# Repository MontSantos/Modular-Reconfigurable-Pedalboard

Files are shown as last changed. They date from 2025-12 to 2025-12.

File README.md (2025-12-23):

# Modular Reconfigurable Pedalboard
A modular, reconfigurable guitar/bass pedalboard designed as a **universal base** for **interchangeable effect modules**.  
Current version includes two analog effect circuits: an **MXR-style Distortion+ inspired clone** and a **silicon Fuzz Face–inspired fuzz**.

---

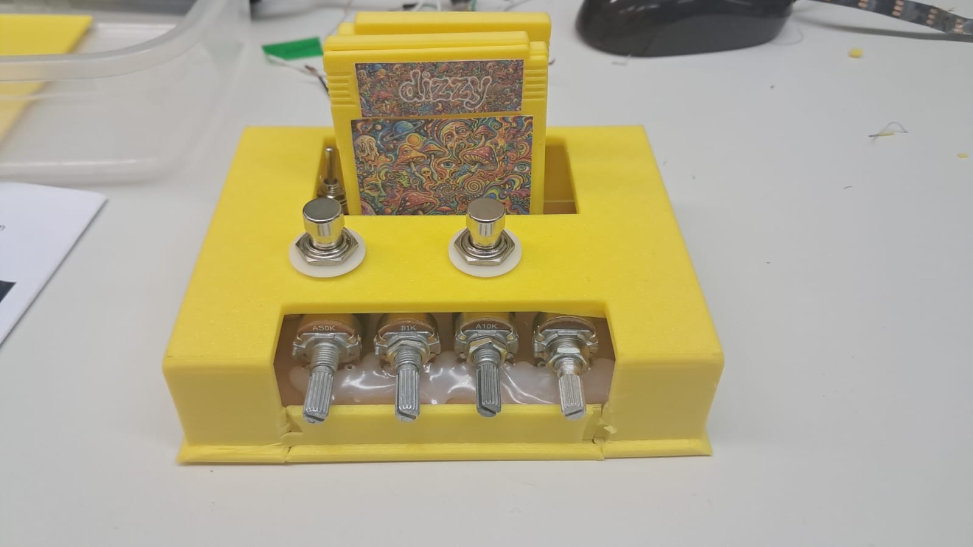
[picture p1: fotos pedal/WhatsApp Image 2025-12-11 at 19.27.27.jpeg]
Pedalboard photo


---

## Features (current)

- A modular board capable of hosting **two 8 pin effect modules** simultaneously
- Two analog effect modules included:
  - **MXR-style distortion** (Distortion+/D+ family inspiration)
  - **Silicon Fuzz Face–inspired fuzz**
- Each module supports **up to two PCB-mounted potentiometers** for onboard control (e.g., Gain/Level, Fuzz/Volume)
- Designed for common use with string instruments, such as **electric guitars** or **basses**
- Fully **customizable** and **open-source** for public access

---

## Repository structure

- `Imagens cartuchos/` - Presents the cover images and logos used to decorate the cartridges
- `PlacaGeral/` — The **main board** (the “placão”): carrier/backplane PCB that hosts the modules and concentrates the shared wiring.
- `Pedais/` — The **effect modules** (schematics/PCB files for Dizzy and Amorphous, and future modules).
- `Modelos pedal/` — Mechanical assets (e.g., templates, outlines, 3D/visual models, and design references).
- `fotos pedal/` — Build photos and progress shots used in the README and documentation.
  
---

## Included effect modules

### 1) **Dizzy** - Silicon Fuzz Face–inspired fuzz 

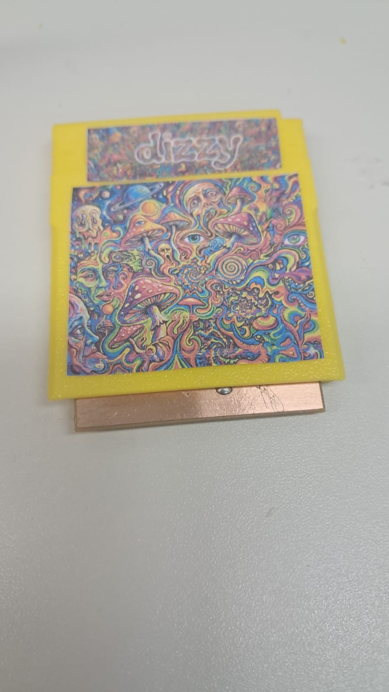
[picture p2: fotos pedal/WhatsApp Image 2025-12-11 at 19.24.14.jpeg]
dizzy


A two-transistor silicon fuzz, implemented with a **negative-ground** power scheme for easy integration with other pedal models.
Great for raw, dirty and aggressive tones.

This module is nicknamed **Dizzy**, referencing the fuzz’s naturally **psychedelic, dizzy aesthetic**.

Reference / inspiration:
- Fuzz Central (Fuzz Face): https://fuzzcentral.ssguitar.com/fuzzface.php

### 2) **Amorphous** - MXR-style distortion (Distortion+ inspired)

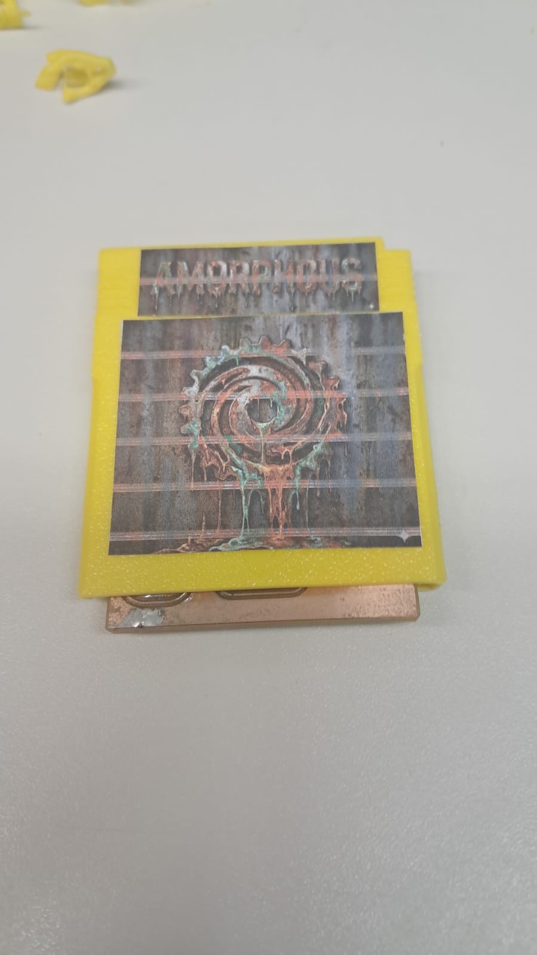
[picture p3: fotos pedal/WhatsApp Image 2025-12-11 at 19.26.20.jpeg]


A classic op-amp gain stage with germanium diode clipping (the “raw” distortion character).  
Useful for gritty tones.  

This module is nicknamed **Amorphous**, referencing how distortion/clipping turns a clean waveform into a denser, less-defined shape.

Reference / inspiration:
- Electrosmash analysis: https://www.electrosmash.com/mxr-distortion-plus-analysis

## The **Main Board**

The **PlacaGeral** is the carrier PCB that turns this project into a modular system. In practice, it works like a small “backplane” for pedals:

- Provides **two module slots** (two 8-pin effect modules at the same time)
- Routes **audio I/O** and keeps a consistent grounding scheme across modules
- Distributes **9V DC power** to the modules (the main board is **center-positive** oriented — double-check before powering)
- Offers a standardized mechanical/electrical base so modules can be swapped without rewiring the whole pedalboard

> ⚠️ Many common pedal supplies are **center-negative**. Do **not** plug a standard center-negative supply into a center-positive board without an adapter/inverter — unless you want to release the magic smoke (and smell something funny).

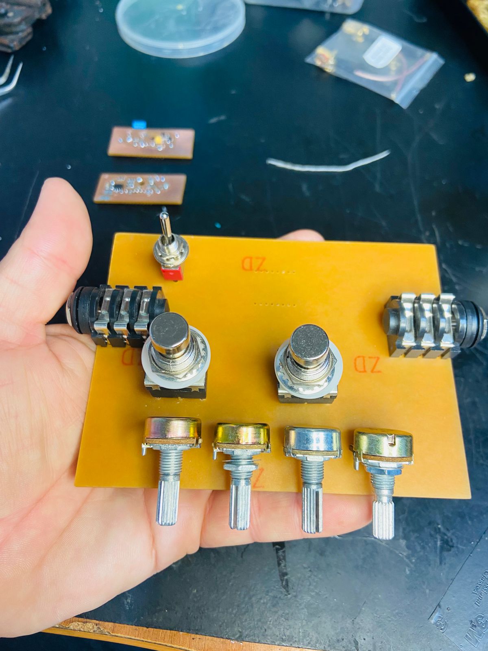
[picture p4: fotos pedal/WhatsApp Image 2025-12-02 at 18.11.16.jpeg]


---

## Cartridge (module holder)

Each effect module is mounted on a removable 3d printed Gameboy inspired **cartridge**, which provides mechanical support and keeps the 8-pin module interface consistent across pedals.

This cartridge was adapted from an existing model available at **(link)** and then modified for this project (fit/clearance/alignment), including:
- alignment tweaks in order to support pedals PCBs.
- clearance changes to avoid collisions with tall components, and parts of the main board structure

Reference / inspiration:
 - [(link)](https://grabcad.com/library/original-gameboy-cartridge)

---

## Power & safety notes

- **Verify supply voltage (9V DC) and polarity** before connecting any power source.
- Before first power-up:
  - Confirm electrolytic/tantalum capacitors orientations.
  - Verify power supply polarity: the main board is **center-positive** oriented.
 
## 3D printed structures notes

It was necessary to modify the case of the **Main board** to accommodate the final board layout. The front piece of the case was cut so the potentiometers could fit in the case. The removed piece was then put back in place once the circuit board was in position.
 
## Electronics hardware notes

During initial bring-up, the main board required a small routing correction: 
 - To properly route the **effect IN/OUT** of each module, it is necessary **cut two traces per pedal** (one affecting the input path and one affecting the output path).  
 - To fix the audio routing, the board was **rewired** (trace cuts + jumper wires) for each module’s input and output.
 - Additionally, the two buffers were removed because they were not handling the signal swing correctly and ended up clipping the **negative half-cycle** of the waveform. This change restored a more symmetric signal path.
This was a quick rework step applied on the assembled board and will be addressed in the next PCB revision.

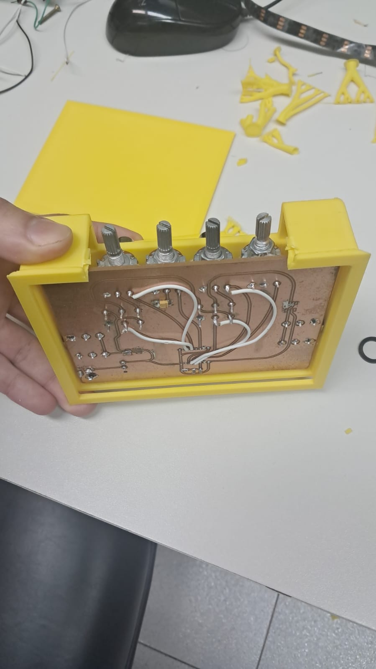
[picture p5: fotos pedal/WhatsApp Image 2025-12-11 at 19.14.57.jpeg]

 
## Credits / Contributions

- **João Neto** — Pedal testing and validation **before** assembling the PCBs (pre print tests).
- **Guilherme Santos** — Pedal testing and validation **before** assembling the PCBs (pre print tests); **PCB design**, **assembly**, and **final testing** of the system.
- **Romulo Soli** — **3D modeling** (enclosure/mechanical models).
- **Yanis** -

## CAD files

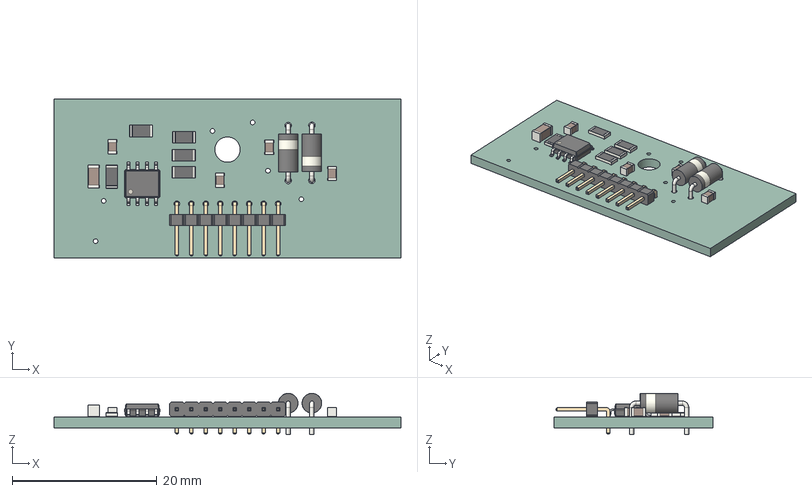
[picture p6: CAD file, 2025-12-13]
Modelos pedal/Modelos pcb/MXRpedal.step
48.0 x 22.0 x 5.71 mm
D_A-405_P7.62mm_Horizontal x 2
R_1206_3216Metric x 5
PinHeader_1x08_P2.00mm_Horizontal
C_0805_2012Metric x 4
C_1206_3216Metric
SOIC-8_3.9x4.9mm_P1.27mm
MXRpedal_PCB

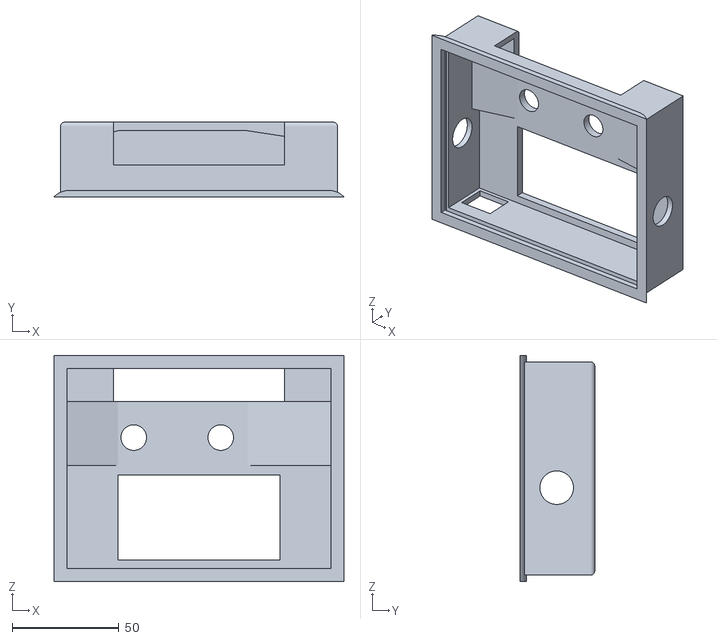
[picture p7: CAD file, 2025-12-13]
Modelos pedal/Modelos STL/SupaCaixa.STL
136.0 x 35.0 x 106.0

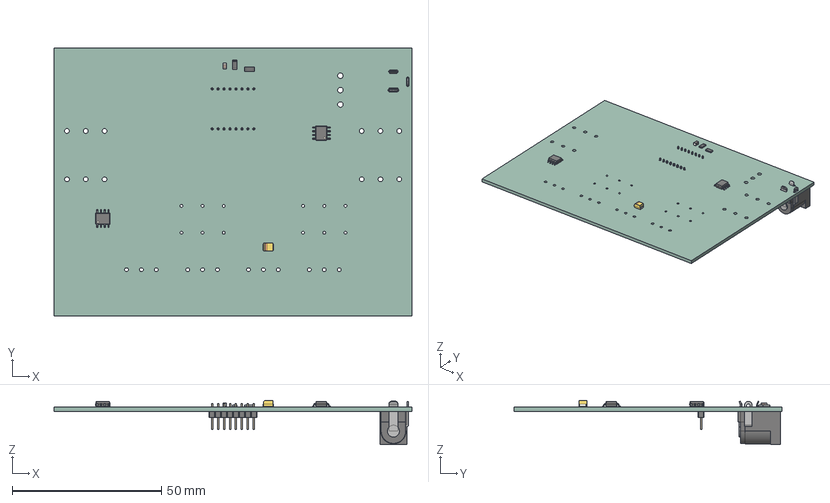
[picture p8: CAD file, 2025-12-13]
Modelos pedal/Modelos pcb/PlacaGeral.step
120.0 x 90.0 x 14.8 mm
R_1206_3216Metric x 2
SOIC-8_3.9x4.9mm_P1.27mm x 2
CP_EIA-3528-21_Kemet-B
C_0805_2012Metric
PinHeader_1x08_P2.00mm_Vertical x 2
BarrelJack_GCT_DCJ200-10-A_Horizontal
PlacaGeral_PCB

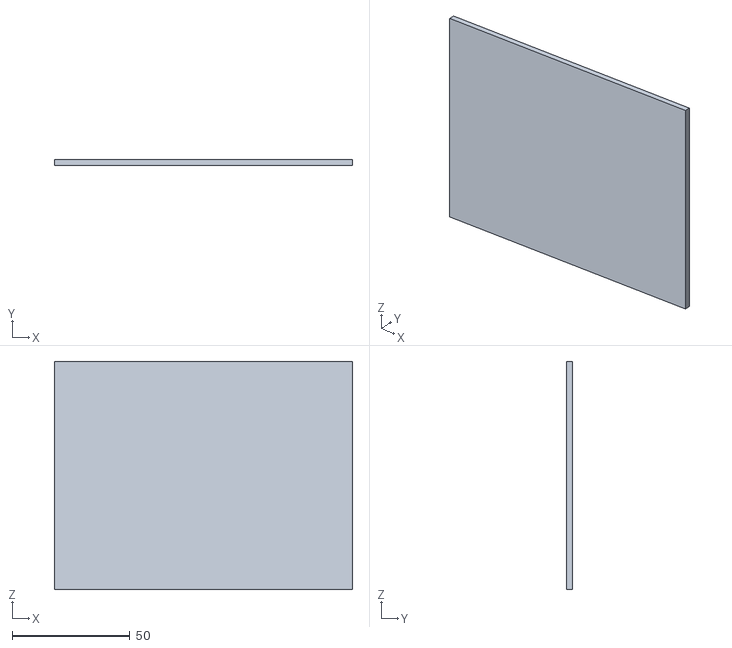
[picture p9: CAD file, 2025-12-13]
Modelos pedal/Modelos STL/CaixaFundo.STL
126.6 x 2.60 x 97.0

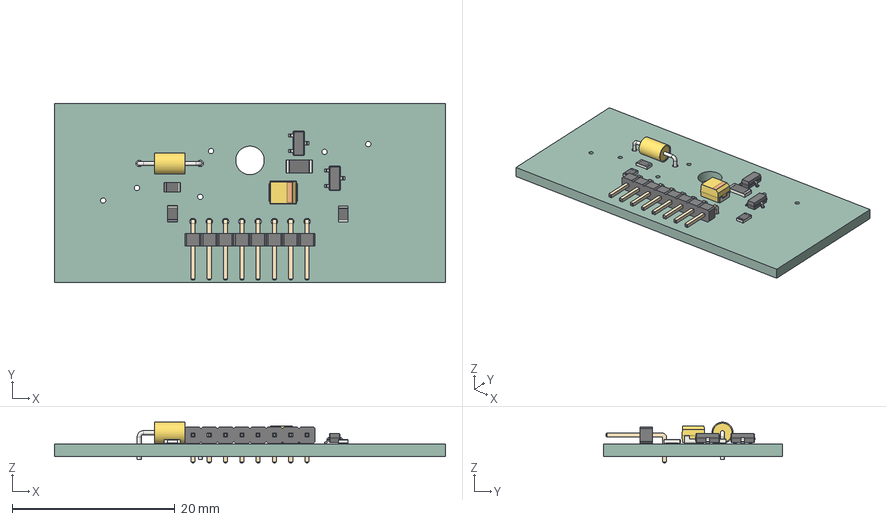
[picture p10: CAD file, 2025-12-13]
Modelos pedal/Modelos pcb/FuzzFace.step
48.0 x 22.0 x 5.00 mm
PinHeader_1x08_P2.00mm_Horizontal
R_1206_3216Metric
R_0805_2012Metric x 3
C_Axial_L3.8mm_D2.6mm_P7.50mm_Horizontal
SOT-23 x 2
CP_EIA-3528-21_Kemet-B
FuzzFace_PCB

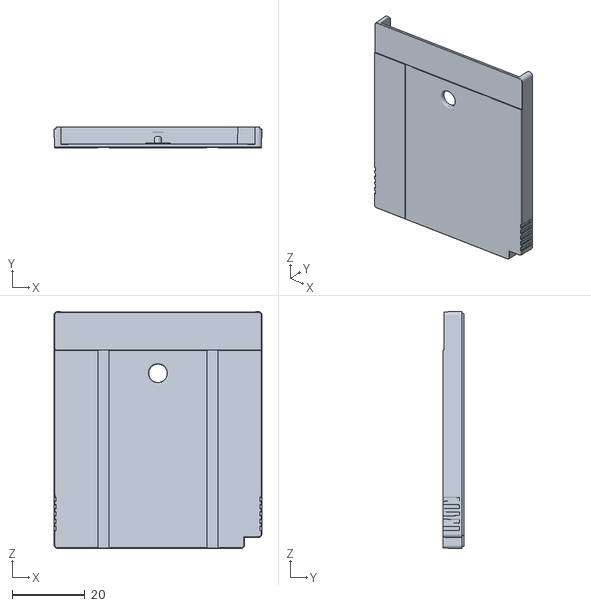
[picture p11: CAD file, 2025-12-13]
Modelos pedal/Modelos STL/GB-Cart_Bottom.stl
57.0 x 5.75 x 65.0

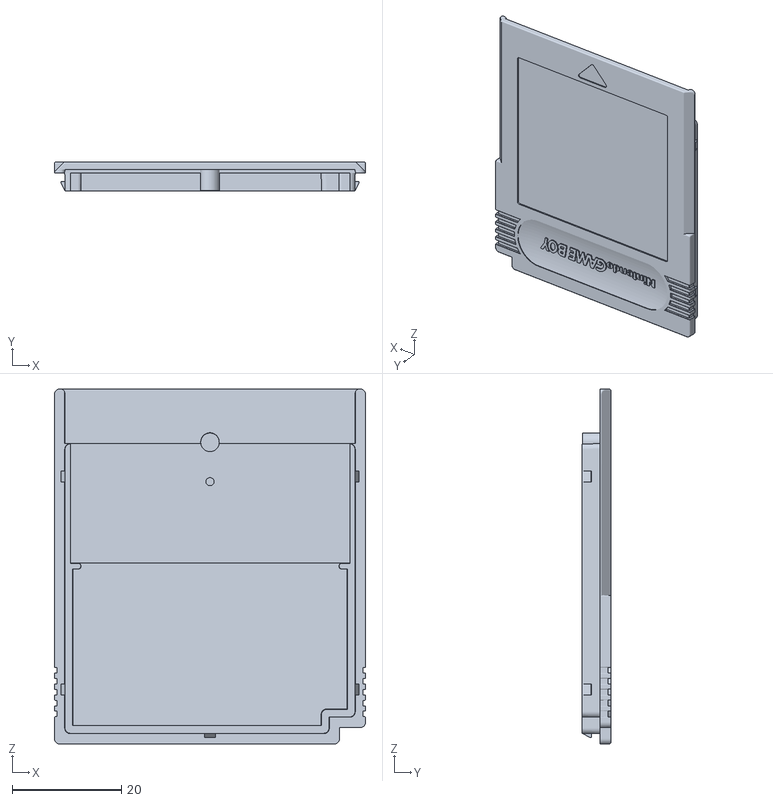
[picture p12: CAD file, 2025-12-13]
Modelos pedal/Modelos STL/GB-Cart_Top.stl
57.0 x 5.30 x 65.0

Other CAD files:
Modelos pedal/Modelos pcb/PlacaGeral.stl

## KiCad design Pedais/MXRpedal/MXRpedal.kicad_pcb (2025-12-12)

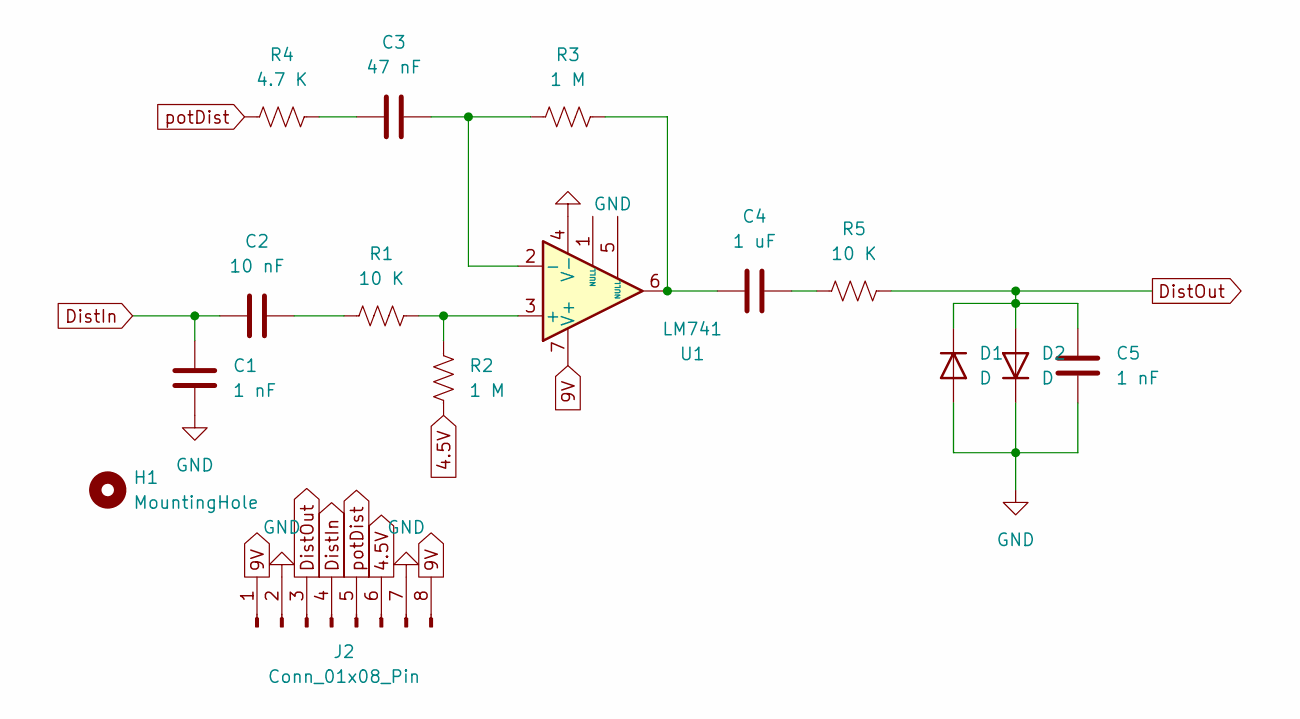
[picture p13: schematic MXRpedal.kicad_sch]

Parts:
C1, C5: 1 nF; C_0805_2012Metric
C2: 10 nF; C_0805_2012Metric
C3: 47 nF; C_1206_3216Metric
C4: 1 uF; C_0805_2012Metric
D1, D2: D; D_A-405_P7.62mm_Horizontal
H1: MountingHole; MountingHole_3.5mm
J2: Conn_01x08_Pin; PinHeader_1x08_P2.00mm_Horizontal
R1, R5: 10 K; R_1206_3216Metric
R2, R3: 1 M; R_1206_3216Metric
R4: 4.7 K; R_1206_3216Metric
U1: LM741; SOIC-8_3.9x4.9mm_P1.27mm

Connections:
4.5V: J2.6, R2.1
9V: J2.1, J2.8, U1.7 (V+)
DistIn: C1.1, C2.1, J2.4
DistOut: C5.2, D1.1 (K), D2.2 (A), J2.3, R5.2
GND: C1.2, C5.1, D1.2 (A), D2.1 (K), J2.2, J2.7, U1.4 (V-)
unnamed: C2.2, R1.1
unnamed: C3.1, R4.2
unnamed: C4.1, R3.2, U1.6
unnamed: C4.2, R5.1
unnamed: R1.2, R2.2, U1.3 (+)
unnamed: C3.2, R3.1, U1.2 (-)
potDist: J2.5, R4.1

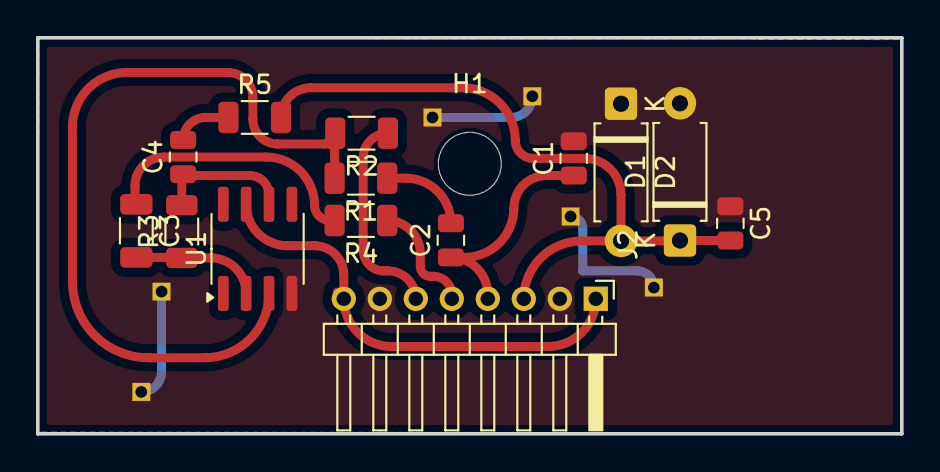
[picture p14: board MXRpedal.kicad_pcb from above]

Board: 2 copper layers, 48.0 x 22.0 mm, 15 parts (0 on the bottom side), 12 nets.

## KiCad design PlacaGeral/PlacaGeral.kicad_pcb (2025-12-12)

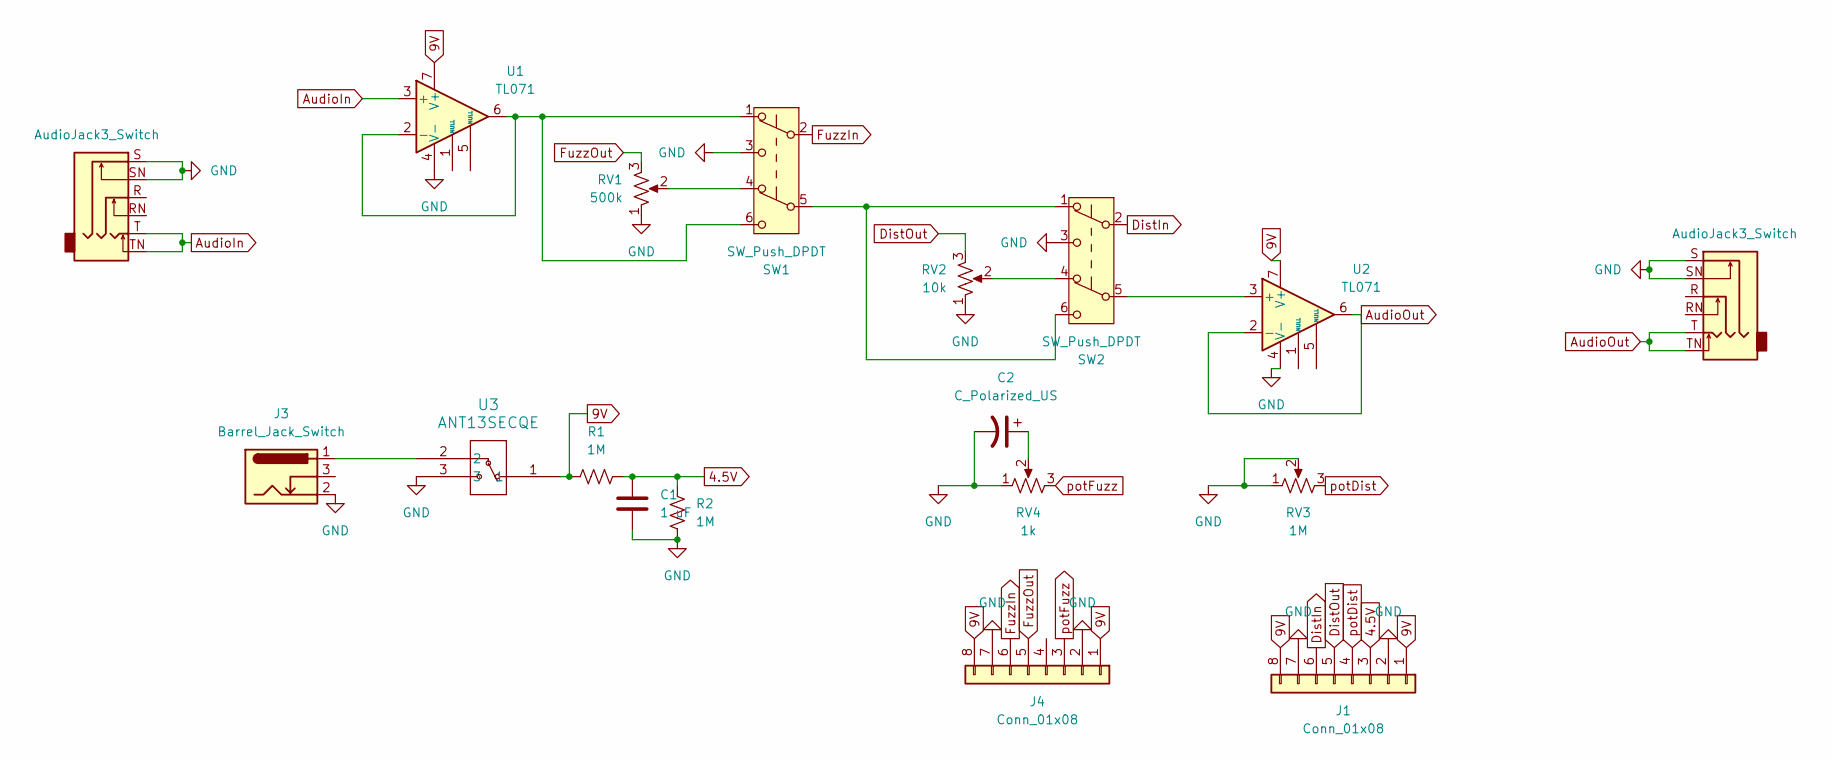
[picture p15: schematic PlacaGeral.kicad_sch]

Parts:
C1: 1 uF; C_0805_2012Metric
C2: C_Polarized_US; CP_EIA-3528-21_Kemet-B
J1, J4: Conn_01x08; PinHeader_1x08_P2.00mm_Vertical
J2, J6: AudioJack3_Switch; PJ-644C
J3: Barrel_Jack_Switch; BarrelJack_GCT_DCJ200-10-A_Horizontal
R1, R2: 1M; R_1206_3216Metric
RV1: 500k; Potentiometer_Piher_PC-16_Single_Horizontal
RV2: 10k; Potentiometer_Piher_PC-16_Single_Horizontal
RV3: 1M; Potentiometer_Piher_PC-16_Single_Horizontal
RV4: 1k; Potentiometer_Piher_PC-16_Single_Horizontal
SW1, SW2: SW_Push_DPDT; pbs24202p
U1, U2: TL071; SOIC-8_3.9x4.9mm_P1.27mm
U3: ANT13SECQE; ANT13SEC_CRS

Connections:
4.5V: C1.1, J1.3, R1.2, R2.2
9V: J1.1, J1.8, J4.1, J4.8, R1.1, U1.7 (V+), U2.7 (V+), U3.1
AudioIn: J6.T, J6.TN, U1.3 (+)
AudioOut: J2.T, J2.TN, U2.2 (-), U2.6
DistIn: J1.6, SW2.2 (B)
DistOut: J1.5, RV2.3
FuzzIn: J4.6, SW1.2 (B)
FuzzOut: J4.5, RV1.3
GND: C1.2, C2.2, J1.2, J1.7, J2.S, J2.SN, J3.2, J4.2, J4.7, J6.S, J6.SN, R2.1, RV1.1, RV2.1, RV3.1, RV3.2, RV4.1, SW1.3 (C), SW2.3 (C), U1.4 (V-), U2.4 (V-), U3.3
unnamed: C2.1, RV4.2
unnamed: J3.1, U3.2
unnamed: RV1.2, SW1.4 (A)
unnamed: RV2.2, SW2.4 (A)
unnamed: SW1.5 (B), SW2.1 (A), SW2.6 (C)
unnamed: SW1.1 (A), SW1.6 (C), U1.2 (-), U1.6
unnamed: SW2.5 (B), U2.3 (+)
potDist: J1.4, RV3.3
potFuzz: J4.3, RV4.3

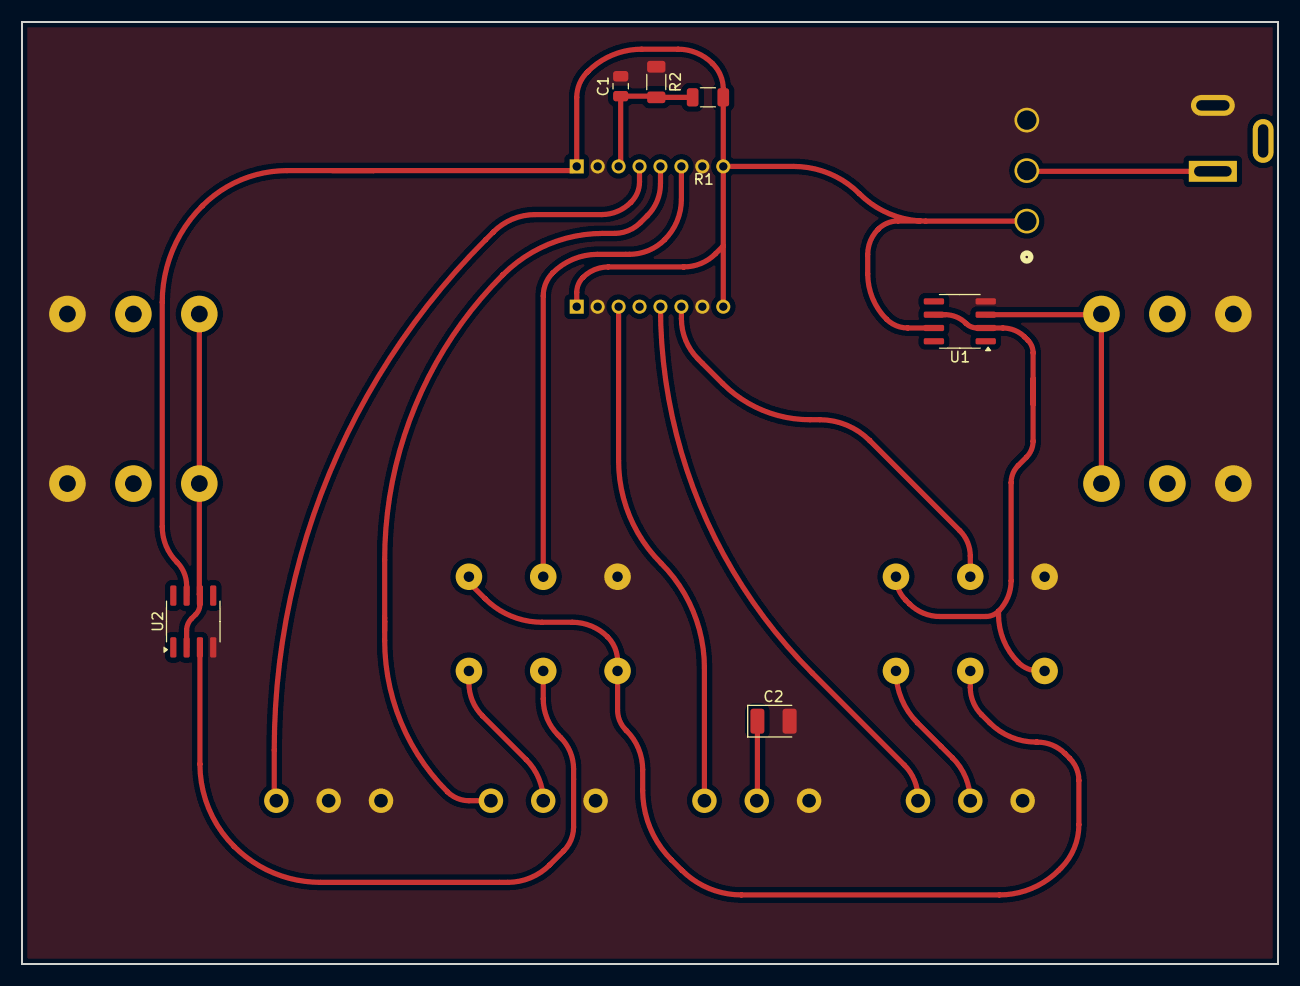
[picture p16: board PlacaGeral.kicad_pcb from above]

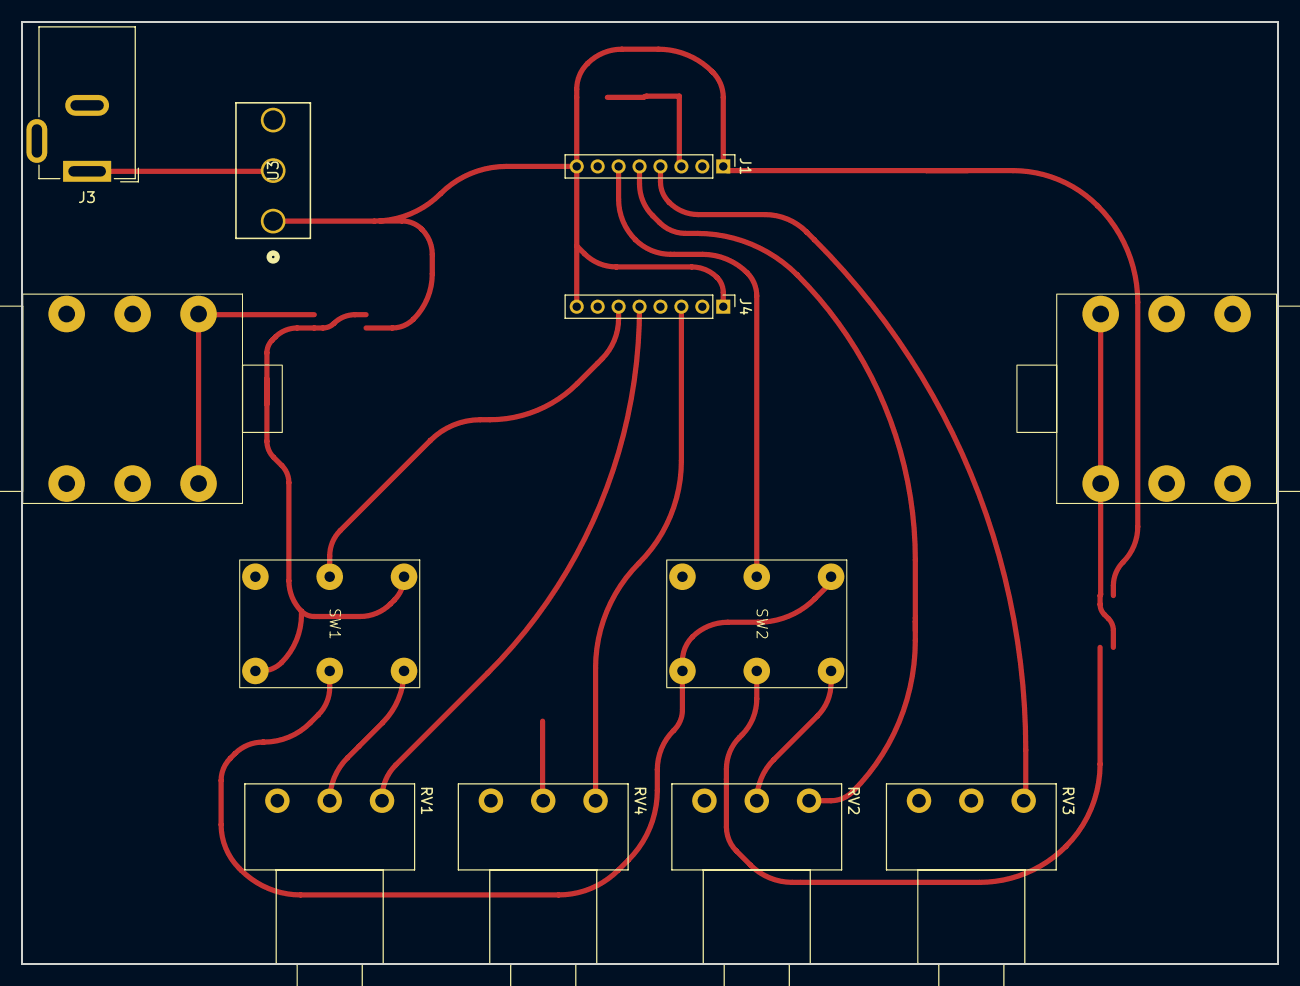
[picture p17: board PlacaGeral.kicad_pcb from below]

Board: 2 copper layers, 120.0 x 90.0 mm, 18 parts (12 on the bottom side), 18 nets.

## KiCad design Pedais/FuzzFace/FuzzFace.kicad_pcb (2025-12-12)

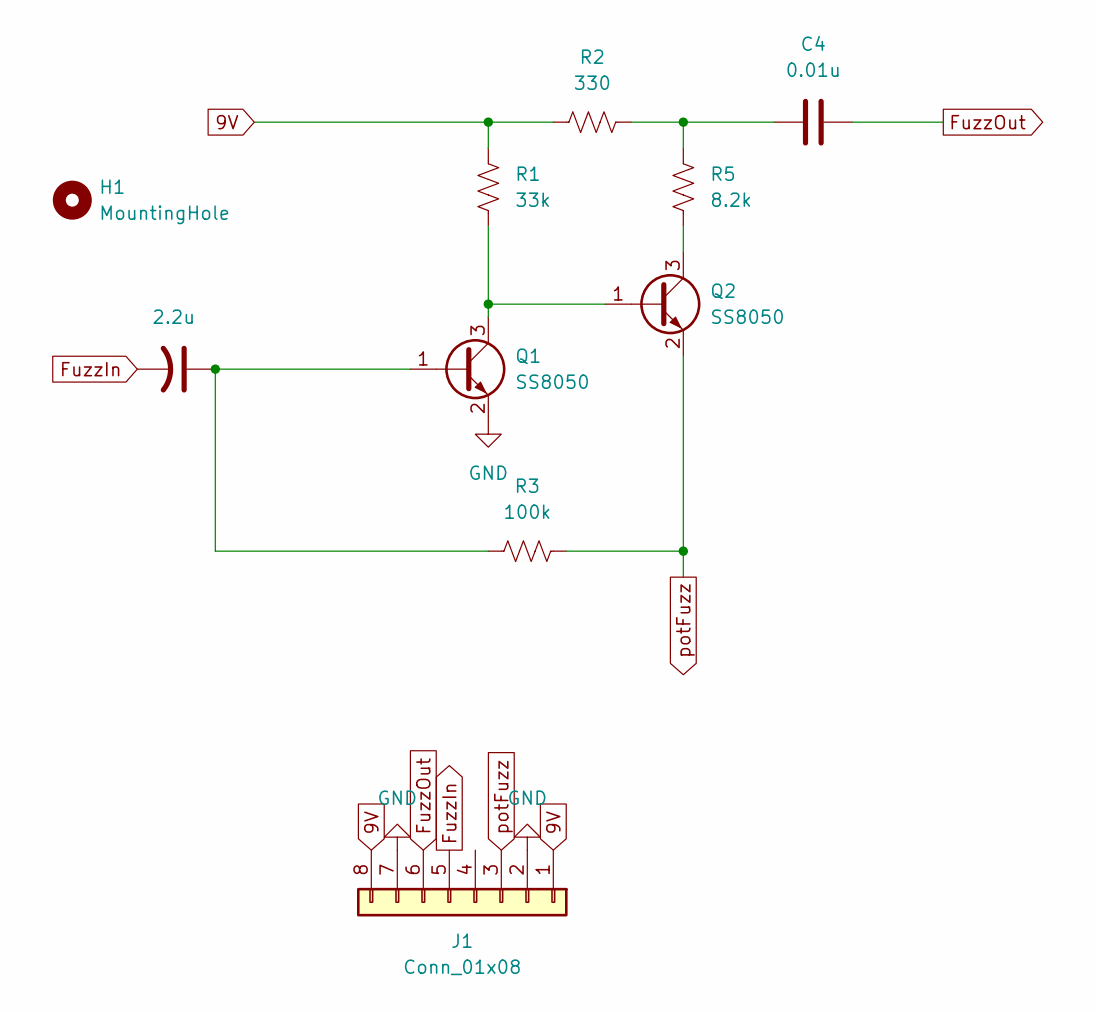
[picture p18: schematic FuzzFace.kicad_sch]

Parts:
C3: 2.2u; CP_EIA-3528-21_Kemet-B_HandSolder
C4: 0.01u; C_Axial_L3.8mm_D2.6mm_P7.50mm_Horizontal
H1: MountingHole; MountingHole_3.5mm
J1: Conn_01x08; PinHeader_1x08_P2.00mm_Horizontal
Q1, Q2: SS8050; SOT-23
R1: 33k; R_0805_2012Metric
R2: 330; R_0805_2012Metric
R3: 100k; R_1206_3216Metric
R5: 8.2k; R_0805_2012Metric

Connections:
9V: J1.1, J1.8, R1.2, R2.1
FuzzIn: C3.2, J1.5
FuzzOut: C4.2, J1.6
GND: J1.2, J1.7, Q1.2 (E)
unnamed: C4.1, R2.2, R5.2
unnamed: C3.1, Q1.1 (B), R3.1
unnamed: Q1.3 (C), Q2.1 (B), R1.1
unnamed: Q2.3 (C), R5.1
potFuzz: J1.3, Q2.2 (E), R3.2

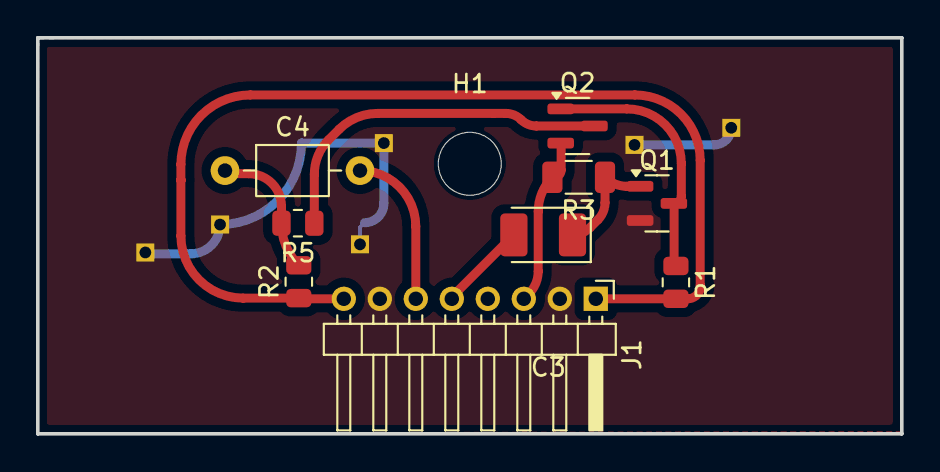
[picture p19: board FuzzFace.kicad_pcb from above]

Board: 2 copper layers, 48.0 x 22.0 mm, 10 parts (0 on the bottom side), 9 nets.
